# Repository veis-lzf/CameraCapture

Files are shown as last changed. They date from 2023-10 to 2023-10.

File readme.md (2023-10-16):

# 语音拍照存储系统

[TOC]

## 简介

- 基于STM32F407+OV2640进行图像采集，然后存储到TF卡中，通过SU-03T语音识别模块对系统进行控制拍照，灯光开关等操作；

- 主要涉及的知识面：

  （1）串口、定时器的使用

  （2）DCMI总线

  （3）SDIO总线

  （4）DMA技术

  （5）单片机原理图和4层PCB设计

  （6）FATFS文件系统

  （6）Trace日志的使用还有串口协议（十六进制串、AT指令）解析

- 目前支持的语音指令：开灯、关灯、一档光、二档光、三档光、拍照

- 语音模块支持二次开发

------

## 系统和电源框图

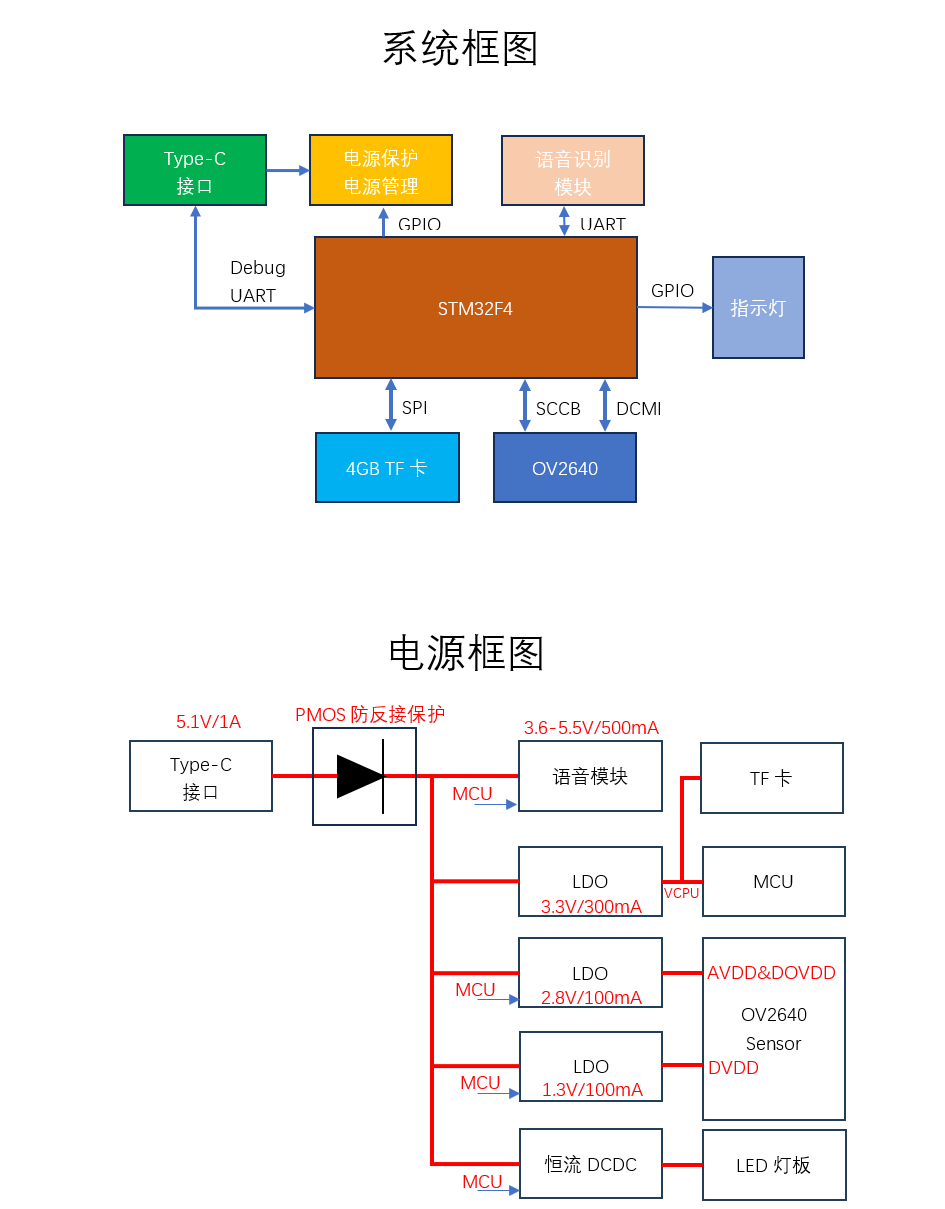
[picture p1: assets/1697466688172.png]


------

## 实物照片

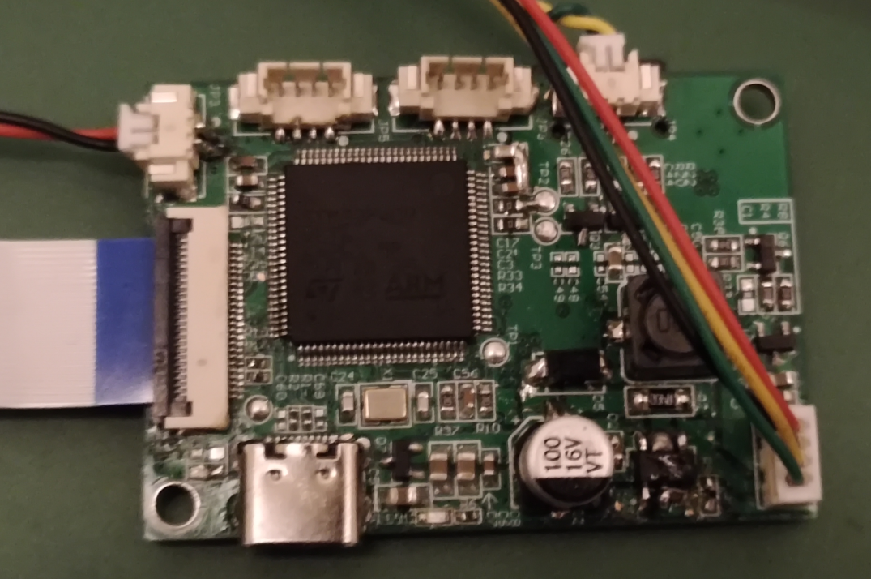
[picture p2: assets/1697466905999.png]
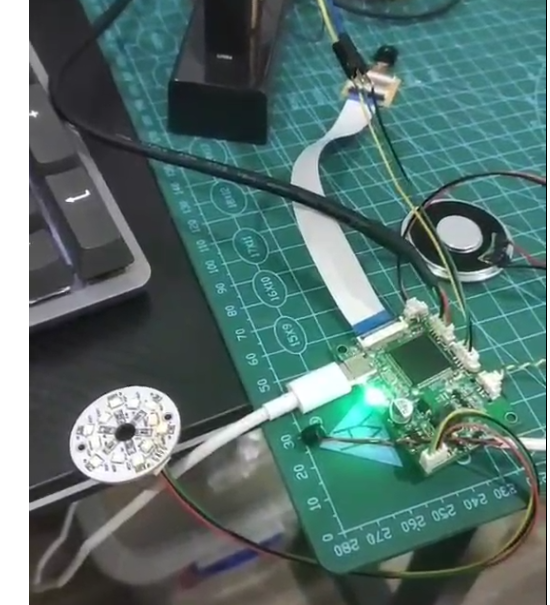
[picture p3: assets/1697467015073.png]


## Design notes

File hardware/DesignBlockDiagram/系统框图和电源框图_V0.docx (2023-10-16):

STM32F4

4GB TF卡

OV2640

SPI

DCMI

SCCB

Type-C

接口

电源保护

电源管理

语音识别

模块

SU-03T

GPIO

UART

指示灯

GPIO

Debug UART

系统框图

Type-C

接口

电源框图

5.1V/1A

语音模块

LDO

3.6-5.5V/500mA

PMOS防反接保护

MCU

3.3V/300mA

LDO

OV2640

Sensor

2.8V/100mA

LDO

1.3V/100mA

DVDD

AVDD&DOVDD

MCU

MCU

MCU

TF卡

VCPU

恒流DCDC

MCU

LED灯板

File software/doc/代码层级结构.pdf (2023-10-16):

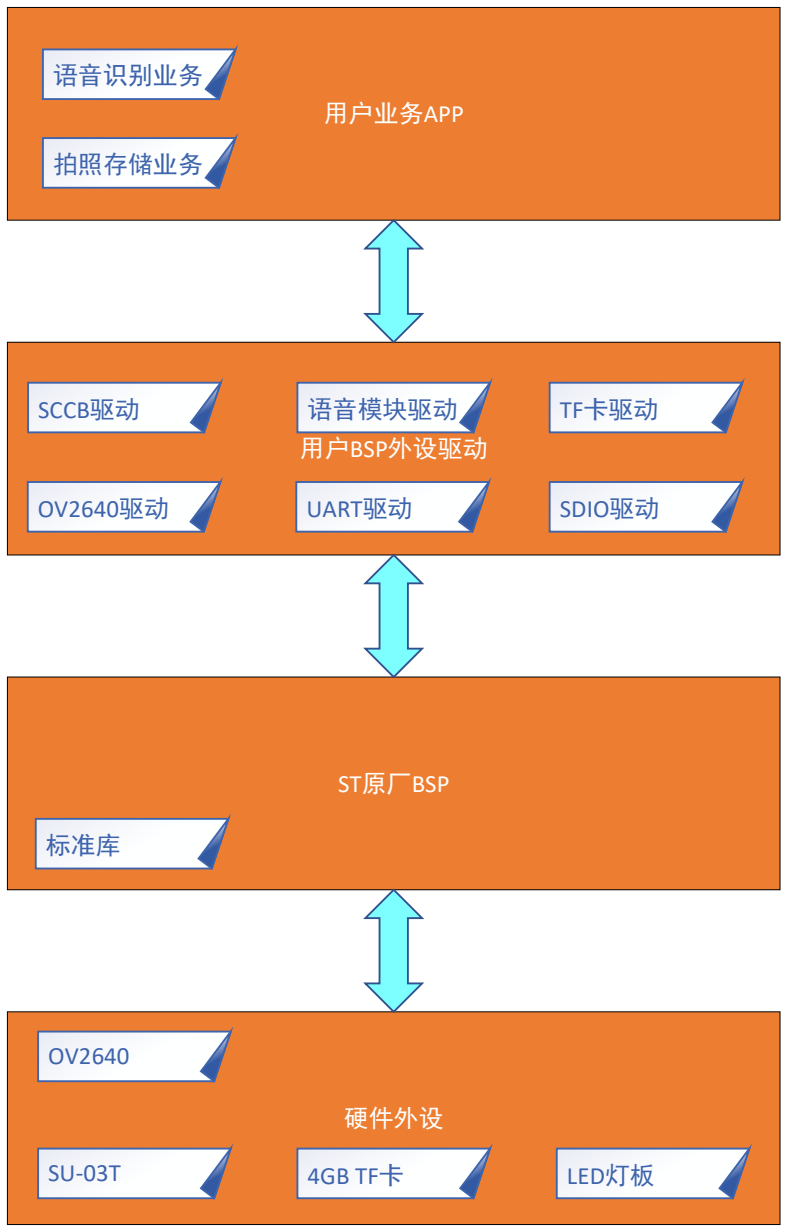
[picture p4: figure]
硬件外设; ST原厂BSP; 用户BSP外设驱动; 用户业务APP; SCCB驱动; 语音模块驱动; UART驱动; SDIO驱动; TF卡驱动; 拍照存储业务; 语音识别业务; 标准库; 4GB TF卡; LED灯板

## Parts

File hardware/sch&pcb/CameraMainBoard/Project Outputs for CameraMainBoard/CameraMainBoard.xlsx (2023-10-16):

Comment | Description | Designator | Footprint | Quantity
1uF | 贴片电容/MLCC电容 | C2, C42 | C0603_M | 2 | 已买
2.2uF | 贴片电容/MLCC电容 | C3, C14, C26 | C0603_M | 3 | 已买
22uF | 贴片电容/MLCC电容 | C5, C6, C7 | C0805_M | 3 | 已买
100nF | 贴片电容/MLCC电容 | C4，C8, C10, C12, C16, C18, C19, C20, C21, C22, C23, C28, C30, C34, C36, C40, C41, C43, C47, C56, C58 | C0603_M | 21 | 已买
10uF | 贴片电容/MLCC电容 | C9, C11, C15, C17, C27, C29, C33, C35, C39, C46, C57 | C0603_M | 11 | 已买
12pF | 贴片电容/MLCC电容 | C24, C25 | C0603_M | 2
SS34 | 肖特基二极管 | D5 | SMA | 1
100uF/16V | 贴片固态电容 | E2 | CS 6*6 - B | 1
TF_Card | TF卡座 | J1 | Micro SD | 1
HDR-1X4 | 4P连接器 | JP1 | MX1.25-L-4P | 1
HDR-1X2 | 2P连接器 | JP3, JP4 | MX1.25-WT-2P | 2
HDR-1X4 | 4P连接器 | JP5, JP6 | MX1.25-LT-4P | 2
33uH | CDRH功率屏蔽电感 | L2 | CDRH74 | 1
电源指示灯 | 贴片LED | LED1 | LED0603_G | 1
SI2301 | P沟道 20V/2.8A | Q1, Q2, Q5, Q7 | SOT23-3N | 4
MMBT3904 | 高频放大-NPN型 | Q3, Q4, Q6 | SOT23-3N | 3
10R | 贴片电阻 | R1, R2 | R0402_M | 2
0R | 贴片电阻 | R3, R11, R12, R13, R16, R19, R33, R34 | R0603_M | 8
100K | 贴片电阻 | R4, R20, R21 | R0603_M | 3
1M | 贴片电阻 | R5 | R0603_M | 1
4.7K | 贴片电阻 | R6 | R0402_M | 1
0.1R | 贴片电阻 | R7 | R1206_M | 1
10K | 贴片电阻 | R8, R9, R10, R14, R26, R27, R37, R39 | R0603_M | 8
1K | 贴片电阻 | R22, R23, R24, R25, R38 | R0603_M | 5
47K | 贴片电阻 | R28, R29, R30, R31, R32 | R0603_M | 5
10R | 贴片电阻 | R35 | R0603_M | 1
XC6228D332VR-G | LDO 1.8V/0.3A | U1 | SOT-23-5 | 1
STM32F407VET6 | ARM Cortex-M4 32b MCU+FPU, 210DMIP, 512 kB Flash, 192+4 kB RAM, Camera, 82 I/Os, 100-pin LQFP, -40 to +85癈, Tray | U2 | LQFP100_V | 1
NS4115 | NS4115 LED恒流驱动IC，最大输出电流1A，输入支持PWM调光 | U4 | SOT89-5M | 1
XC6219B132MR | LDO 1.8V/0.3A | U5 | SOT-23-5 | 1
XC6219B282MR | LDO 1.8V/0.3A | U6 | SOT-23-5 | 1
OV2640 |  | U7 | OV2640-24 | 1
SU-03T | 离线语音识别模块V1.8 | U8 | SU-03T | 1
TYPE-C 2.0 -16P | USB2.0_Type-C_16Pin母座 | USBC1 | USB-C-SMD_16P | 1
8M | 4脚无源晶振(谐振器） | X1 | XTAL-3225-4P | 1
24.000Mhz | 有源晶振 | Y1 | XTAL3225 | 1

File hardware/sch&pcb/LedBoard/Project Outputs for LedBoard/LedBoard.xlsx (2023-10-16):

Comment | Description | Designator | Footprint | LibRef | Quantity
HDR-1X4 | 4P连接器 | JP1 | MX1.25-L-4P | Header 4 | 1
2835 | 0.2W 功率LED | LED1, LED2, LED3, LED4, LED5, LED6, LED7, LED8, LED9, LED10, LED11, LED12 | LED 2835-2P | LED-2835 | 12
100R | 贴片电阻 | R1, R2, R3, R4, R5, R6 | R0603_L | R | 6
1R | 贴片电阻 | R7, R8, R9, R10, R11, R12 | R1206_L | R | 6

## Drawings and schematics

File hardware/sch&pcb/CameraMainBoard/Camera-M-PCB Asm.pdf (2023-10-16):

1 | 1
Material | Layer | Thickness Dielectric Material Type | Gerber

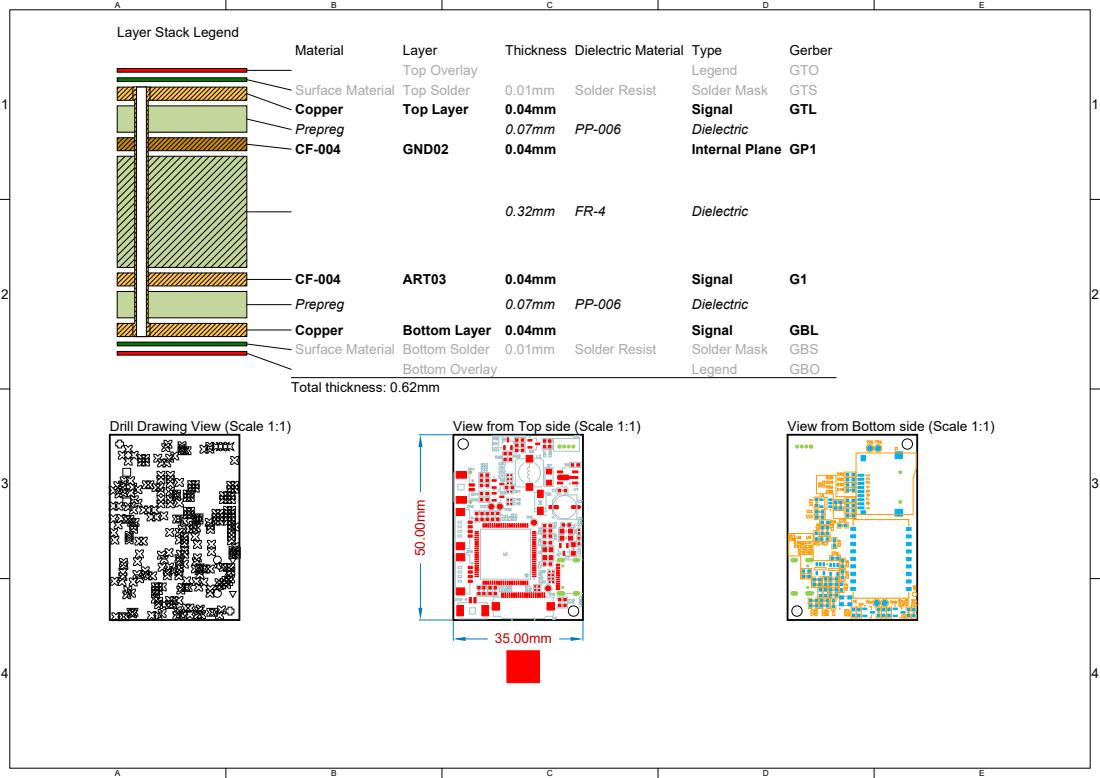
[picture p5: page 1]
Drill Drawing View (Scale 1:1); View from Top side (Scale 1:1); View from Bottom side (Scale 1:1); Top Overlay; Legend; GTO; Surface Material Top Solder; Solder Resist; Solder Mask; GTS; Copper; Top Layer; Signal; GTL; Prepreg; Dielectric; GND02; Internal Plane GP1; ART03; Bottom Layer 0.04mm; GBL; Surface Material Bottom Solder 0.01mm; GBS; Bottom Overlay; GBO; Total thickness: 0.62mm

Layer Stack Legend

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
| Designator | Comment
| C1, C13, C32, C38, C44, C45, C55 | 10nF/NC | Quantity 72313
| C2, C42 | 1uF
| C3, C14, C26 | 2.2uF
Line # 123456789 | C4 | 0.1uF
| C5, C6, C7 | 22uF
| C8, C10, C12, C16, C18, C19, C20, C21, C22, C23, C28, C30, C34, C36, C40, C41, C43, C47, C56, C58 | 100nF | 20
| C9, C11, C15, C17, C27, C29, C33, C35, C39, C46, C57 | 10uF
| C24, C25 | 12pF
| C48, C49, C50, C51, C52, C53, C54, C59, C60 | NC
10 | D5 | SS34
11 | E2 | 100uF/16V
12 | J1 | TF_Card
13 | JP1, JP5, JP6 | HDR-1X4
14 | JP3, JP4 | HDR-1X2
15 | L2 | 33uH
16 | LED1 | 灯灯灯灯灯
17 | Q1, Q2, Q5, Q7 | SI2301
18 | Q3, Q4, Q6 | MMBT3904
19 | R1, R2, R35 | 10R | 1129111321143383131175511221111111111111
20 | R3, R11, R12, R13, R16, R19, R33, R34 | 0R
21 | R4, R20, R21 | 100K
22 | R5 | 1M
23 | R6, R15, R17 | 4.7K
24 | R7 | 0.1R
25 | R8 | 10K
26 | R9, R10, R14, R26, R27, R37, R39 | 10K
27 | R22, R23, R24, R25, R38 | 1K
28 | R28, R29, R30, R31, R32 | 47K
29 | R36 | 4.7K/NC
30 | TP1 | BOOT0
31 | TP2, TP6 | RXD
32 | TP3, TP5 | TXD
33 | TP7 | JTMS
34 | TP8 | JTCK
35 | TP9 | VCPU
36 | U1 | XC6228D332VR-G
37 | U2 | STM32F407VET6
38 | U4 | NS4115
39 | U5 | XC6219B132MR
40 | U6 | XC6219B282MR
41 | U7 | OV2640
42 | U8 | SU-03T
43 | USBC1 | TYPE-C 2.0 -16P
44 | X1 | 8M
45 | Y1 | 24.000Mhz

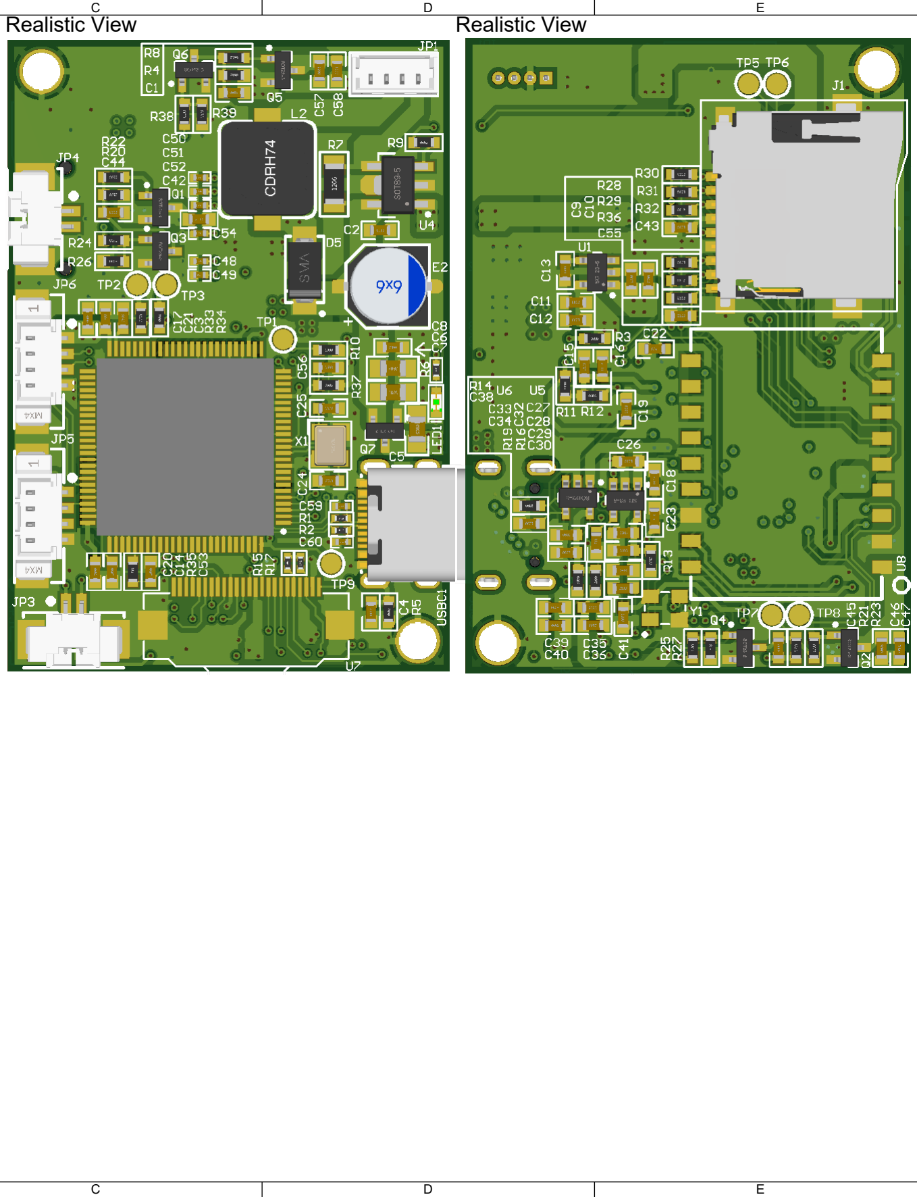
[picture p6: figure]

Bill Of Materials | Realistic View | Realistic View

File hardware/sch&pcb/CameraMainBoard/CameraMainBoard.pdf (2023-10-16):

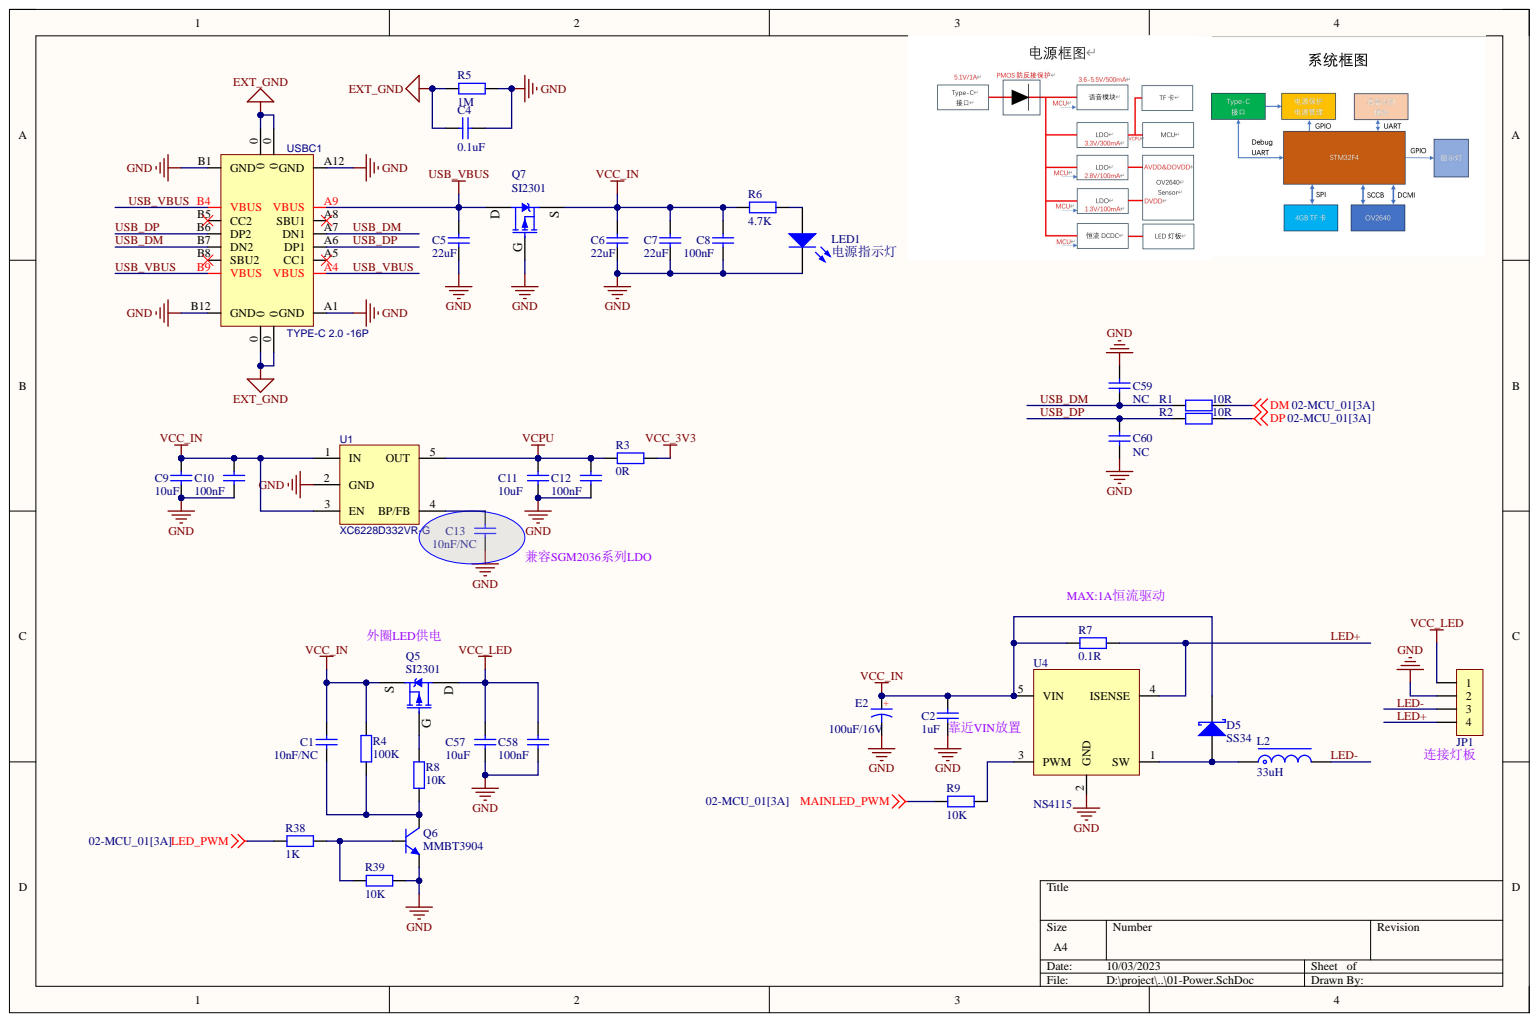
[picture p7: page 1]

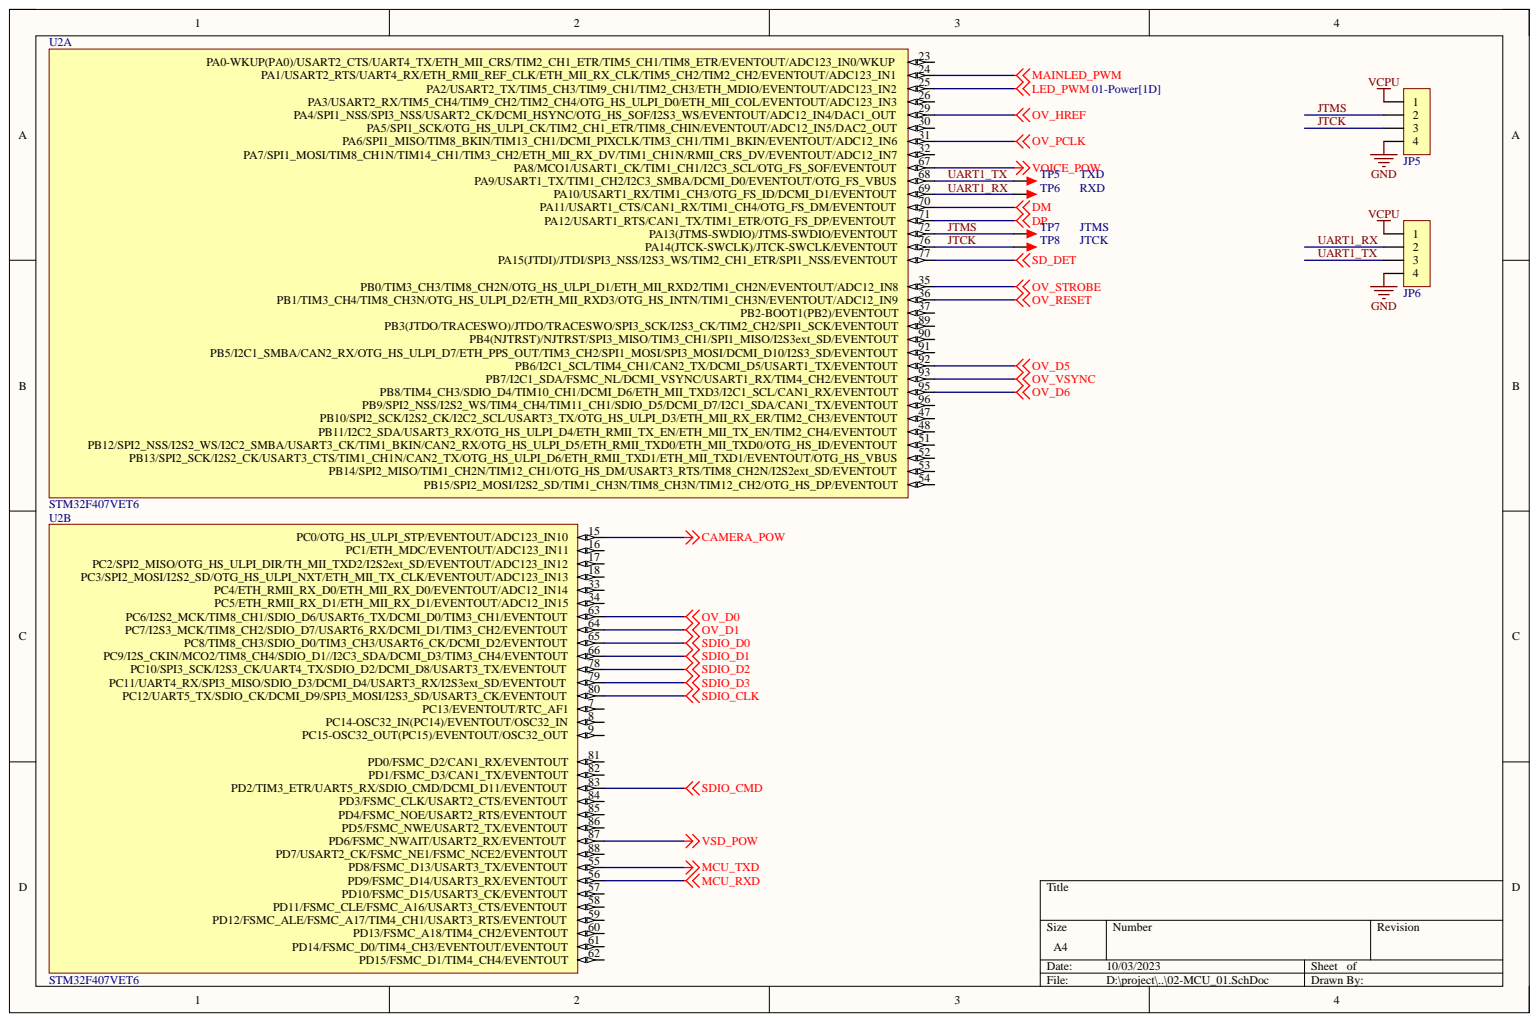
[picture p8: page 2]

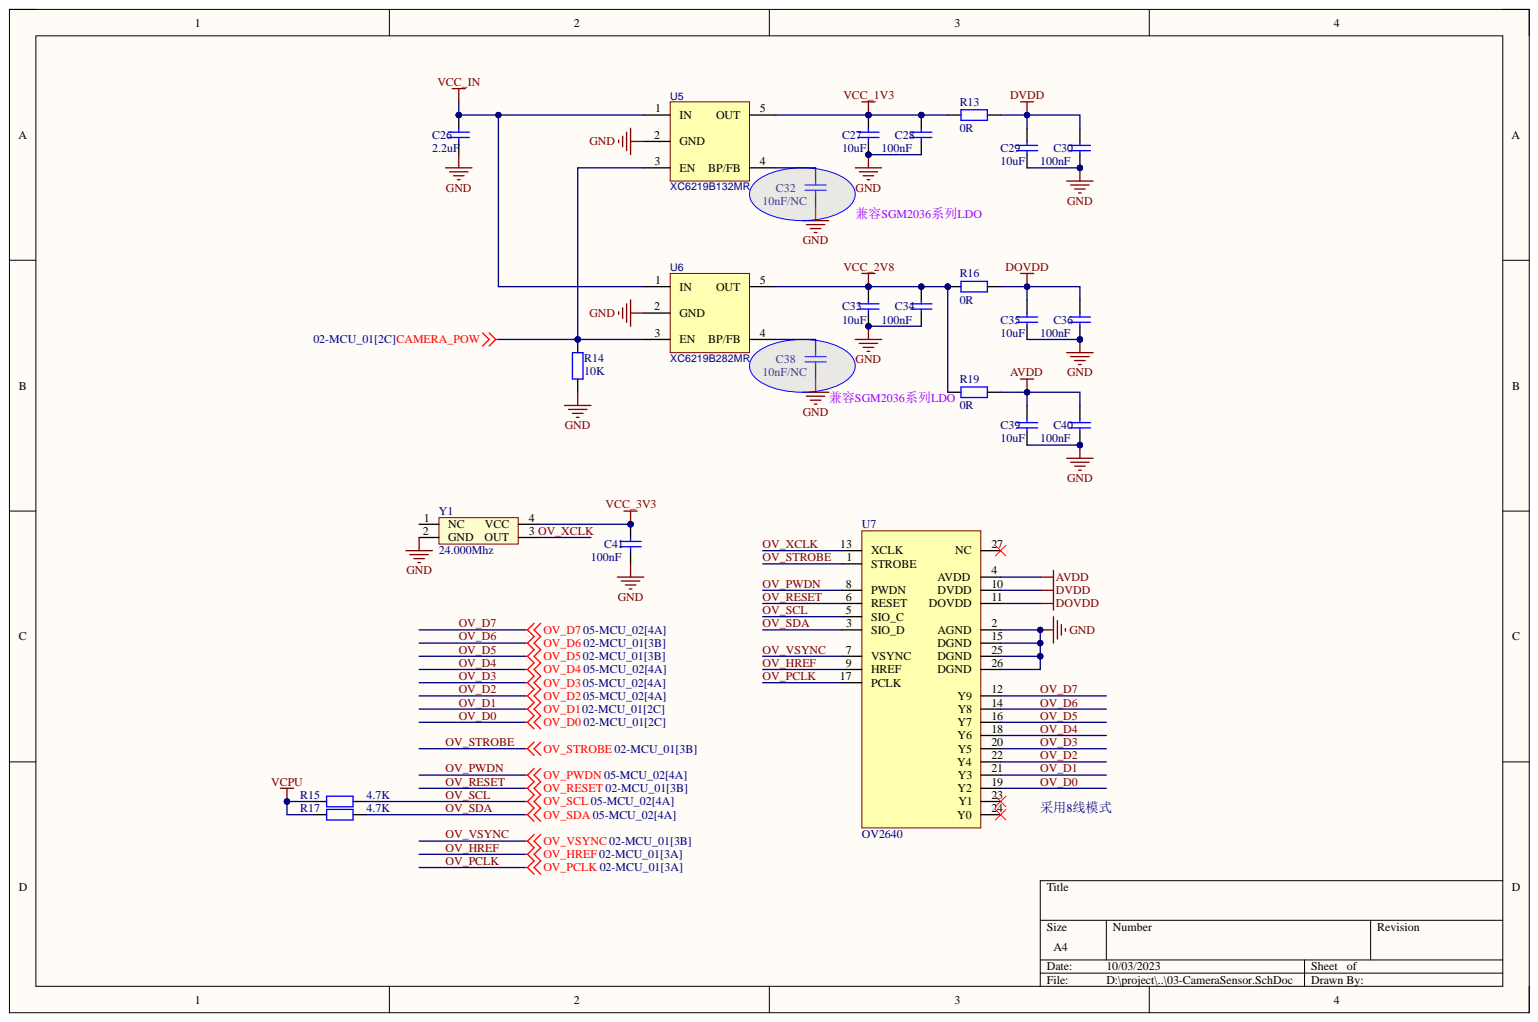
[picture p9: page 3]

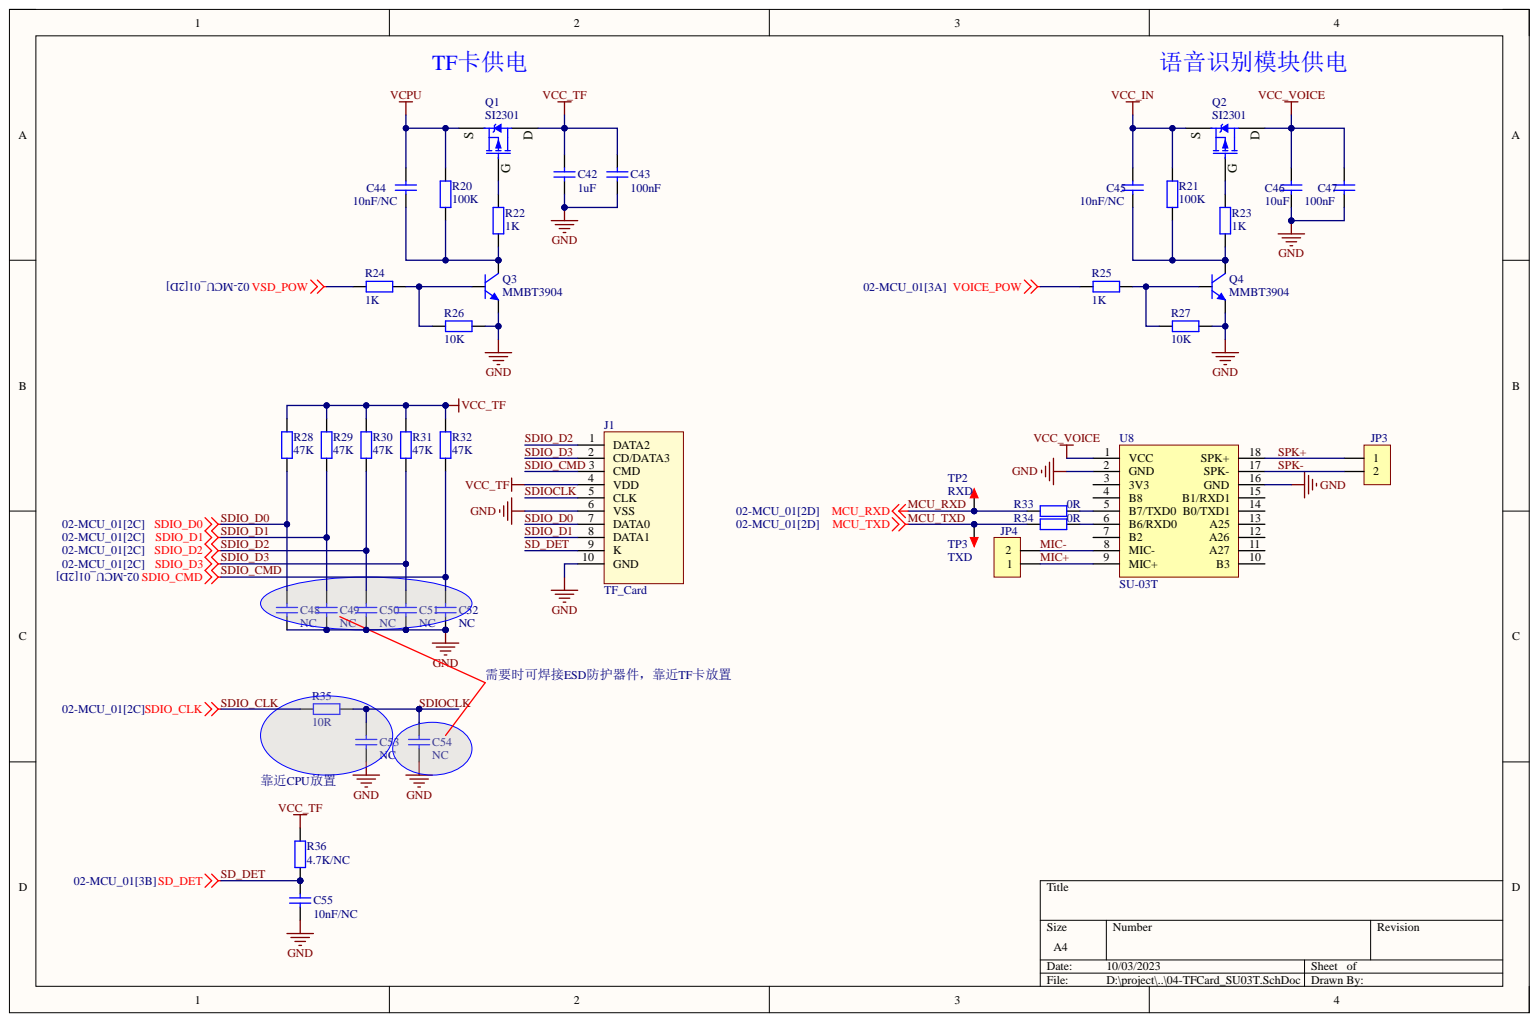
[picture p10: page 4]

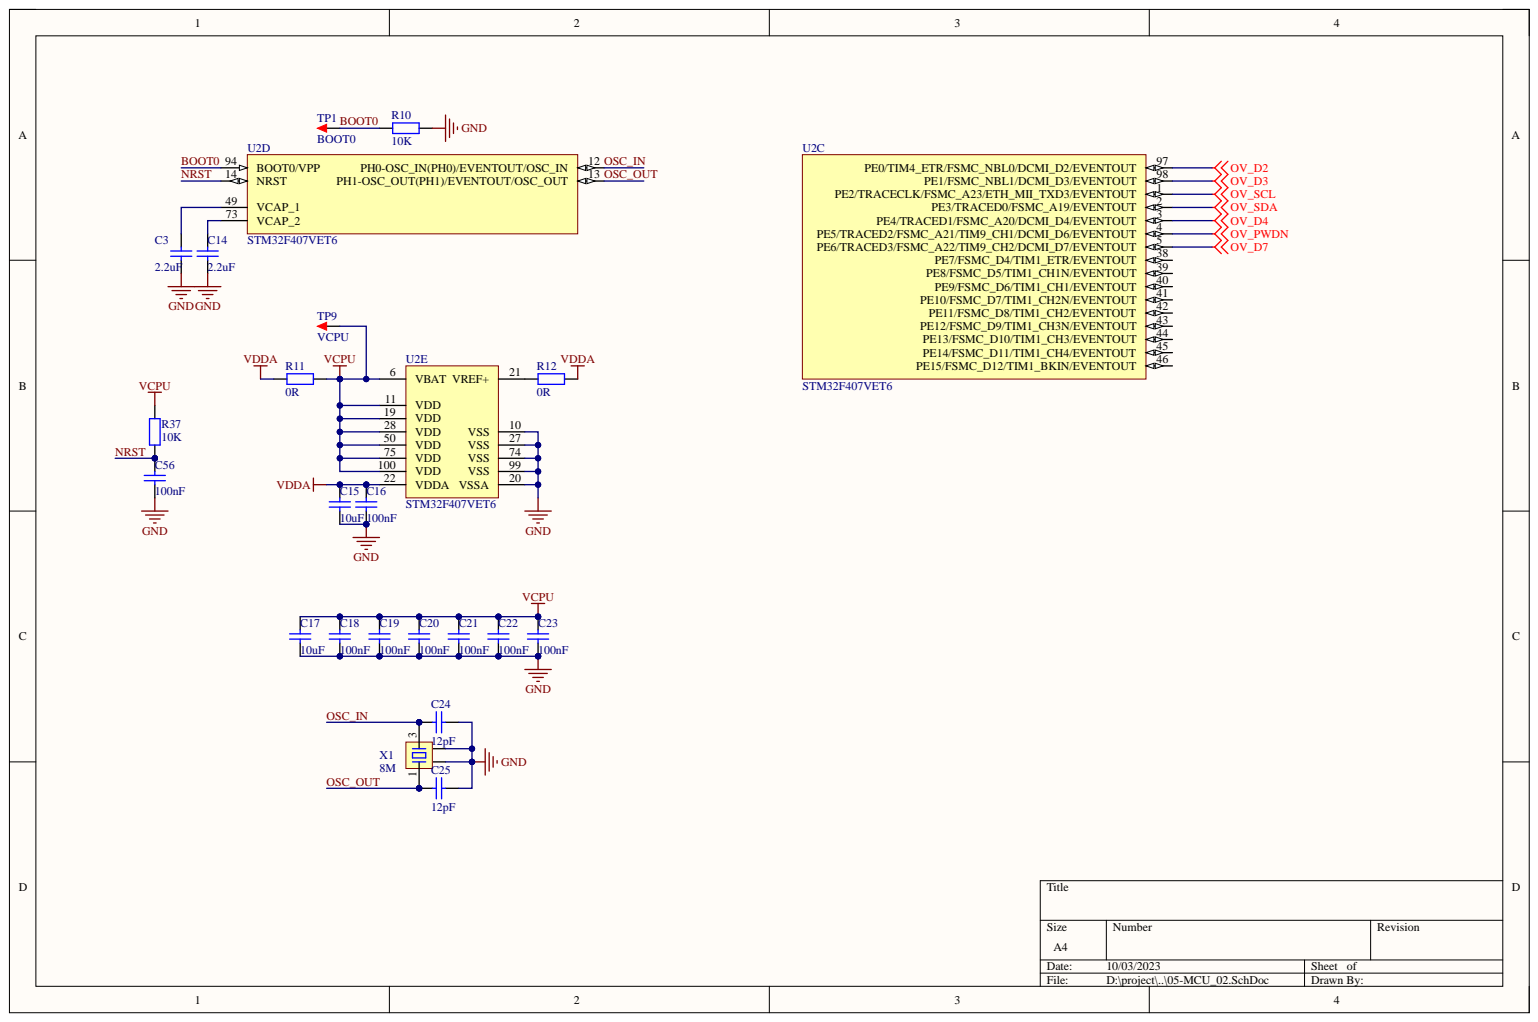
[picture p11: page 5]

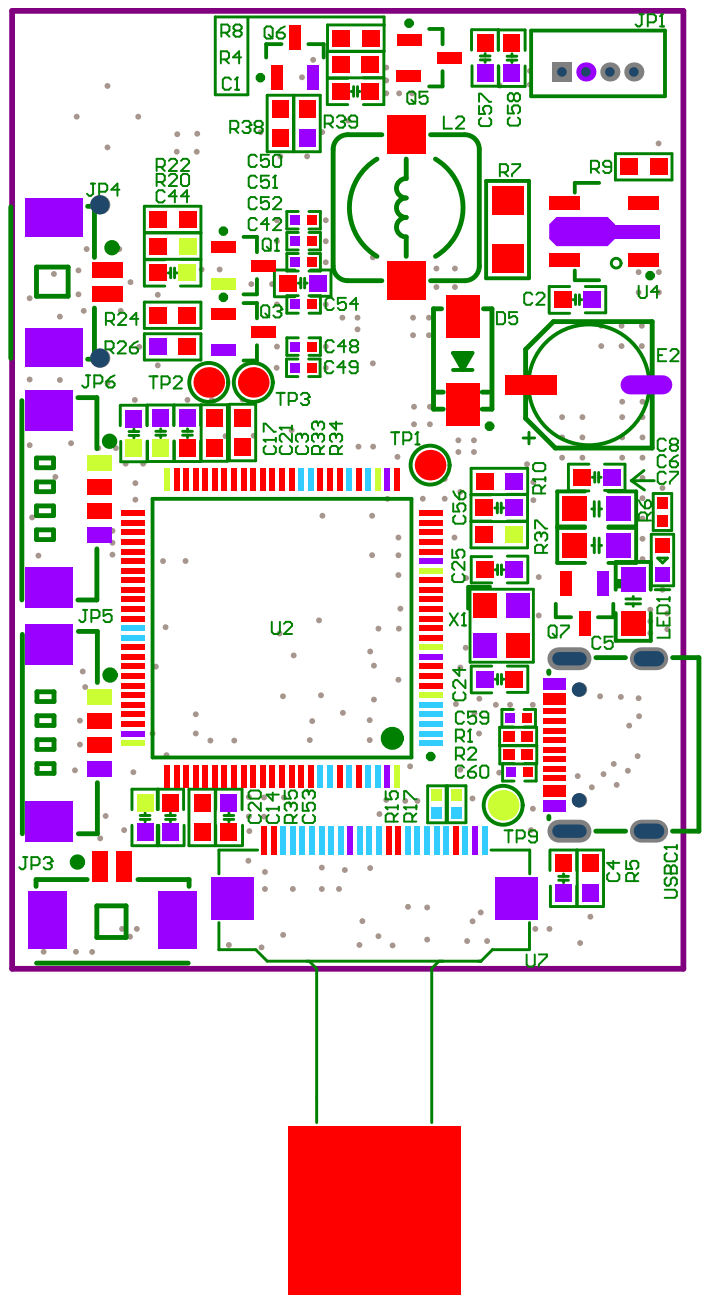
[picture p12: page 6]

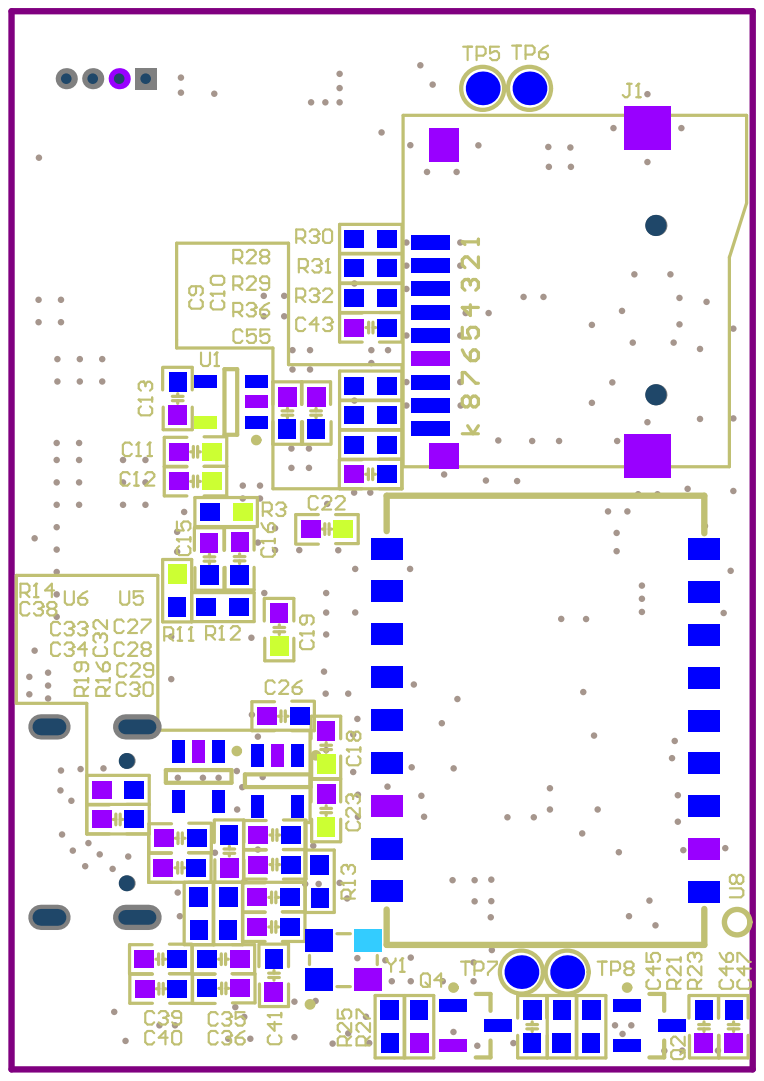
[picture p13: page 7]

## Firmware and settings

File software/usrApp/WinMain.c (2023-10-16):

#include "WinMain.h"
#include "debug.h"

#define VERSION	"V1.0.1"

uint8_t frame_err = 0;

void dcmi_rx_callback(void)
{
	uint32_t i;
	uint32_t *pbuf;
	pbuf = jpeg_data_buf + jpeg_data_len;//偏移到有效数据末尾
	if(DMA2_Stream1->CR&(1<<19))//buf0已满,正常处理buf1
	{ 
		for(i=0;i<jpeg_dma_bufsize;i++)pbuf[i] = jpeg_buf0[i];//读取buf0里面的数据
		jpeg_data_len += jpeg_dma_bufsize;//偏移
	}else //buf1已满,正常处理buf0
	{
		for(i=0;i<jpeg_dma_bufsize;i++)pbuf[i] = jpeg_buf1[i];//读取buf1里面的数据
		jpeg_data_len += jpeg_dma_bufsize;//偏移 
	} 	
}

void Capture_CpltCallback(void)
{
	uint32_t i;
	uint32_t rlen; // 剩余数据长度
	uint32_t *pbuf;
	if(jpeg_data_ok == CAPTURE_BUSY) // jpeg数据还未采集完?
    {	
		DMA_Cmd(DMA2_Stream1,DISABLE);		// 停止当前传输
		while(DMA_GetCmdStatus(DMA2_Stream1) != DISABLE);	// 等待DMA2_Stream1可配置 
		rlen=jpeg_dma_bufsize-DMA_GetCurrDataCounter(DMA2_Stream1); // 得到剩余数据长度	
		pbuf=jpeg_data_buf+jpeg_data_len; // 偏移到有效数据末尾,继续添加
		if(DMA2_Stream1->CR&(1<<19))
			for(i=0;i<rlen;i++)pbuf[i]=jpeg_buf1[i];  // 读取buf1里面的剩余数据
		else for(i=0;i<rlen;i++)pbuf[i]=jpeg_buf0[i]; // 读取buf0里面的剩余数据 
		jpeg_data_len+=rlen;			// 加上剩余长度
		jpeg_data_ok = CAPTURE_COMPLETE; // 标记JPEG数据采集完按成,等待其他函数处理
    }
    if(jpeg_data_ok == PROCESS_COMPLETE) // 上一次的jpeg数据已经被处理了
    {
		DMA_SetCurrDataCounter(DMA2_Stream1,jpeg_dma_bufsize); // 传输长度为jpeg_buf_size*4字节
		DMA_Cmd(DMA2_Stream1,ENABLE); // 重新传输
		jpeg_data_ok = CAPTURE_BUSY;  // 标记数据未采集
		jpeg_data_len = 0;			  // 数据重新开始
	}
}

static void init(void *param)
{
	RCC_ClocksTypeDef RCC_ClocksStatus;

	driver_misc_init();	  // 初始化系统时基/GPIO时钟/NVIC分组
	usr_gpio_init(); 	  // 初始化外设端口	
	my_mem_init(SRAMIN);  // 初始化内部内存池 
	my_mem_init(SRAMCCM); // 初始化CCM内存池
	misc_init(); // 初始化外设驱动
	
	jpeg_buf0 = mymalloc(SRAMIN,jpeg_dma_bufsize*4);	//为jpeg dma接收申请内存	
	jpeg_buf1 = mymalloc(SRAMIN,jpeg_dma_bufsize*4);	//为jpeg dma接收申请内存	
	jpeg_data_buf = mymalloc(SRAMIN, 30*1024);		//为jpeg文件申请内存(最大300KB)
	pname = mymalloc(SRAMIN,30); // 为带路径的文件名分配30个字节的内存
	
	// 打印复位原因
//	check_rst_stat();
	// 打印系统频率
	RCC_GetClocksFreq(&RCC_ClocksStatus);
	p_dbg(
		"\r\nVERSION:%s\r\n"
		"SYSCLK_Frequency:%d\r\n"
		"HCLK_Frequency:%d\r\n"
		"PCLK1_Frequency:%d\r\n"
		"PCLK2_Frequency:%d\r\n",
		VERSION,
		RCC_ClocksStatus.SYSCLK_Frequency, 
		RCC_ClocksStatus.HCLK_Frequency, 
		RCC_ClocksStatus.PCLK1_Frequency, 
		RCC_ClocksStatus.PCLK2_Frequency);
		
	Init_SDCARD();
	
	uint8_t timeout = 0;
	while(OV2640_Init() && timeout < 10)
	{
		timeout++;
		gpio_set_level((uint32_t)CAMERA_PWR_PORT_GROUP, CAMERA_PWR_PIN, LOW_LEVEL);
		delay_ms(200);
		gpio_set_level((uint32_t)CAMERA_PWR_PORT_GROUP, CAMERA_PWR_PIN, HIGH_LEVEL);
		delay_ms(200);
	}
	if(timeout == 10)
	{
		p_err("ov2640 init failed!");
		soft_reset();
	}
}

//#define JPEG_UART_TX_TEST
#ifdef JPEG_UART_TX_TEST
// JPEG测试
// JPEG数据,通过串口1发送给电脑.
void jpeg_test(void)
{	
	uint32_t i, jpeg_start, jpeg_len, jpeg_ok;; 
	uint8_t *p;
	
	DCMI_DMA_Init((u32)jpeg_buf0,(u32)jpeg_buf1,jpeg_dma_bufsize,DMA_MemoryDataSize_Word,DMA_MemoryInc_Enable);//DCMI DMA配置(双缓冲模式)
	Init_JPEG(eType_QVGA);
	OV2640_JPEG_Mode();		//切换为JPEG模式 
	DCMI_Start(); 			//启动传输 
	while(1)
	{
		IWDG_Feed();
		if(jpeg_data_ok==1)	// 已经采集完一帧图像了
		{  
			p=(uint8_t*)jpeg_data_buf;
			for(i=0;i<jpeg_data_len*4;i++)//查找0XFF,0XD8
			{
				//printf("%x ", pbuf[i]);
				if((p[i]==0XFF)&&(p[i+1]==0XD8))
				{
					jpeg_start = i;
				}
				if((p[i]==0XFF)&&(p[i+1]==0XD9))
				{
					jpeg_len = i - jpeg_start + 2;
					jpeg_ok = 1;
					break;
				}
			}
			
			if(jpeg_ok)
			{
				p += jpeg_start;
				for(i=0;i<jpeg_len;i++)		                            // dma传输1次等于4字节,所以乘以4.
				{
					while(USART_GetFlagStatus(USART1,USART_FLAG_TC)==RESET);	// 循环发送,直到发送完毕  		
					USART_SendData(USART1,p[i]); 
					IWDG_Feed();
				}
			}
			else
			{
				frame_err++;
			}
			jpeg_data_ok=2;
		} 
    }
} 
#endif

uint8_t run_status = 0;
static void run(void *param)
{
	DCMI_DMA_Init((u32)jpeg_buf0,(u32)jpeg_buf1,jpeg_dma_bufsize,DMA_MemoryDataSize_Word,DMA_MemoryInc_Enable);//DCMI DMA配置(双缓冲模式)
	Init_JPEG(eType_QVGA);
	OV2640_JPEG_Mode();		//切换为JPEG模式 
	DCMI_Start(); 			//启动传输
	
	WDT_init(IWDG_Prescaler_256, 500); // 预分频数为64,重载值为500,溢出时间为1s
	
	while(1)
	{
		IWDG_Feed();
		delay_ms(1*1000);
	#ifdef JPEG_UART_TX_TEST
		jpeg_test();
	#endif
	}
}

WinMainStruct mainTask =
{
	init,
	run,
};

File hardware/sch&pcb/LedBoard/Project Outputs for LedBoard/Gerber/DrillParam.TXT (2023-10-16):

M48
;Layer_Color=9474304
;FILE_FORMAT=4:4
METRIC,LZ
;TYPE=PLATED
T1F00S00C0.5000
%
T01
X0010795Y0005207
X0009984Y00061582
X0009173Y00071094
X00083619Y00080606
M30

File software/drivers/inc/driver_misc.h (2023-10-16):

#ifndef __DRIVER_MISC_H__
#define __DRIVER_MISC_H__

#include "type.h"

///////////////////////////////////////////////////////////////////////////////////////////////////////////////
#define GPIO_SET(port,pin) (port->BSRRL = pin)
#define GPIO_CLR(port,pin) (port->BSRRH = pin)
#define GPIO_STAT(port,pin)(!!(port->IDR & pin))

typedef enum 
{
	LOW_LEVEL = 0,
	HIGH_LEVEL,
} GPIO_Level;
///////////////////////////////////////////////////////////////////////////////////////////////////////////////

#define SD_CARD_STATUS_ERROR	0
#define SD_CARD_STATUS_OK		1

//define UART PORT
// 用于调试日志输出
#define UART1_RX_PORT_GROUP 		GPIOA
#define UART1_TX_PORT_GROUP 		GPIOA
#define UART1_TX_PIN 				GPIO_Pin_9
#define UART1_RX_PIN 				GPIO_Pin_10
#define UART1_TX_PIN_SOURSE			GPIO_PinSource9
#define UART1_RX_PIN_SOURSE			GPIO_PinSource10

// 用于语音模块
#define UART3_RX_PORT_GROUP 		GPIOD
#define UART3_TX_PORT_GROUP 		GPIOD
#define UART3_TX_PIN 				GPIO_Pin_8
#define UART3_RX_PIN 				GPIO_Pin_9
#define UART3_TX_PIN_SOURSE			GPIO_PinSource8
#define UART3_RX_PIN_SOURSE			GPIO_PinSource9

//define USB PORT

#define USB_DP_PORT_GROUP 		GPIOA
#define USB_DM_PORT_GROUP 		GPIOA

#define USB_DP_PIN 				GPIO_Pin_12
#define USB_DM_PIN 				GPIO_Pin_11

#define USB_DP_PIN_SOURSE		GPIO_PinSource12
#define USB_DM_PIN_SOURSE		GPIO_PinSource11

//define sdio PORT

#define SDIO_CLK_PORT				GPIOC
#define SDIO_CLK_PIN				GPIO_Pin_12
#define SDIO_CLK_SOURCE				GPIO_PinSource12

#define SDIO_D0_PORT				GPIOC
#define SDIO_D0_PIN					GPIO_Pin_8
#define SDIO_D0_SOURCE				GPIO_PinSource8

#define SDIO_D1_PORT				GPIOC
#define SDIO_D1_PIN					GPIO_Pin_9
#define SDIO_D1_SOURCE				GPIO_PinSource9

#define SDIO_D2_PORT				GPIOC
#define SDIO_D2_PIN					GPIO_Pin_10
#define SDIO_D2_SOURCE				GPIO_PinSource10

#define SDIO_D3_PORT				GPIOC
#define SDIO_D3_PIN					GPIO_Pin_11
#define SDIO_D3_SOURCE				GPIO_PinSource11

#define SDIO_CMD_PORT				GPIOD
#define SDIO_CMD_PIN				GPIO_Pin_2
#define SDIO_CMD_SOURCE				GPIO_PinSource2

#define SD_DET_PORT					GPIOA
#define SD_DET_PIN					GPIO_Pin_15
#define SD_DET_SOURCE				GPIO_PinSource15
//end define sdio PORT

//define DCMI PORT
#define DCMI_HS_PORT_GROUP 			GPIOA
#define DCMI_HS_PIN 				GPIO_Pin_4
#define DCMI_HS_SOURCE 				GPIO_PinSource4

#define DCMI_VS_PORT_GROUP 			GPIOB
#define DCMI_VS_PIN 				GPIO_Pin_7
#define DCMI_VS_SOURCE 				GPIO_PinSource7

#define DCMI_PCLK_PORT_GROUP 		GPIOA
#define DCMI_PCLK_PIN 				GPIO_Pin_6
#define DCMI_PCLK_SOURCE 			GPIO_PinSource6

#define DCMI_D0_PORT_GROUP 			GPIOC
#define DCMI_D0_PIN 				GPIO_Pin_6
#define DCMI_D0_SOURCE 				GPIO_PinSource6

#define DCMI_D1_PORT_GROUP 			GPIOC
#define DCMI_D1_PIN 				GPIO_Pin_7
#define DCMI_D1_SOURCE 				GPIO_PinSource7
		
#define DCMI_D2_PORT_GROUP 			GPIOE
#define DCMI_D2_PIN 				GPIO_Pin_0
#define DCMI_D2_SOURCE 				GPIO_PinSource0
		
#define DCMI_D3_PORT_GROUP 			GPIOE
#define DCMI_D3_PIN 				GPIO_Pin_1
#define DCMI_D3_SOURCE 				GPIO_PinSource1
		
#define DCMI_D4_PORT_GROUP 			GPIOE
#define DCMI_D4_PIN 				GPIO_Pin_4
#define DCMI_D4_SOURCE 				GPIO_PinSource4
		
#define DCMI_D5_PORT_GROUP 			GPIOB
#define DCMI_D5_PIN 				GPIO_Pin_6
#define DCMI_D5_SOURCE 				GPIO_PinSource6
		
#define DCMI_D6_PORT_GROUP 			GPIOB
#define DCMI_D6_PIN 				GPIO_Pin_8
#define DCMI_D6_SOURCE 				GPIO_PinSource8
		
#define DCMI_D7_PORT_GROUP 			GPIOE
#define DCMI_D7_PIN 				GPIO_Pin_6
#define DCMI_D7_SOURCE 				GPIO_PinSource6

// 摄像头采用外部晶振，不配置此时钟输出
#define MCO_PORT_GROUP 		 		NULL
#define MCO_PIN 					NULL
#define MCO_PIN_SOURCE 				NULL

// 闪光灯控制引脚（预留）
#define STROBE_PORT_GROUP 		 	GPIOB
#define STROBE_PIN 					GPIO_Pin_0

#define DCMI_RST_PORT_GROUP 		GPIOB
#define DCMI_RST_PIN 				GPIO_Pin_1
	
#define DCMI_PWD_PORT_GROUP 		GPIOE
#define DCMI_PWD_PIN				GPIO_Pin_5
	
#define SIO_C_PORT_GROUP 			GPIOE
#define SIO_C_PIN 					GPIO_Pin_2
	
#define SIO_D_PORT_GROUP 			GPIOE
#define SIO_D_PIN 					GPIO_Pin_3

#define SIO_D_OUT					gpio_cfg((uint32_t)SIO_D_PORT_GROUP, SIO_D_PIN, GPIO_Mode_Out_PP);
#define SIO_D_IN					gpio_cfg((uint32_t)SIO_D_PORT_GROUP, SIO_D_PIN, GPIO_Mode_IPU);

//end define DCMI PORT

//define power PORT

// 摄像头电源使能，高开低关
#define CAMERA_PWR_PORT_GROUP 		GPIOC
#define CAMERA_PWR_PIN 				GPIO_Pin_0

// TF卡电源使能，高开低关
#define VSD_POW_PORT_GROUP			GPIOD
#define VSD_POW_PIN 				GPIO_Pin_6

// SU-03T语音识别模块电源使能，高开低关
#define VOICE_POW_PORT_GROUP		GPIOA
#define VOICE_POW_PIN 				GPIO_Pin_8

//end define power PORT

//define pwm PORT
#define MAIN_LED_PWM_PORT_GROUP		GPIOA
#define MAIN_LED_PWM_PIN			GPIO_Pin_1
#define MAIN_LED_PWM_SOURCE 		GPIO_PinSource1
#define MAIN_LED_PWM_AF				GPIO_AF_TIM2

#define LED_PWM_PORT_GROUP			GPIOA
#define LED_PWM_PIN					GPIO_Pin_2
#define LED_PWM_SOURCE 				GPIO_PinSource2
#define LED_PWM_AF					GPIO_AF_TIM2

//end define pwm PORT

void gpio_cfg(uint32_t group, uint32_t pin, uint8_t mode);
void gpio_set_level(uint32_t group, uint32_t pin, GPIO_Level level);
void usr_gpio_init(void);
int check_rst_stat(void);
void driver_misc_init(void);
uint32_t get_random(void);
void driver_gpio_init(void);
void _mem_init(void);
uint32_t get_us_count(void);

#endif

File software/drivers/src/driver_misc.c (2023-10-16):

#define DEBUG

#include "debug.h"
#include "drivers.h"
#include "app.h"

#include <absacc.h>

// 系统节拍
#define OS_TICK_RATE_HZ	(1000)

extern char Image$$RW_IRAM1$$ZI$$Limit[];
void _mem_init(void)
{
#if 0
	uint32_t malloc_start, malloc_size;

	malloc_start = (uint32_t) &Image$$RW_IRAM1$$ZI$$Limit; //取空闲内存最低地址
	malloc_start = (malloc_start + 3) & (~0x03);// ALIGN TO word

	// 0x20000为板子内存总大小，更换MCU时需注意
	// malloc_size = 0x20000000 + (128*1024) - malloc_start;
	// @veis20230416, stm32f427vit6 sram size=256(112+16+64+64(ccm))KB
	malloc_size = 0x20000000 + (192*1024) - malloc_start;

/*
*407有64k的高速ram(地址0x10000000)，由于其不能用于DMA等外设使用，所以不建议放入内存池
*建议手动分配使用
*/
	sys_meminit((void*)0x10000000, 0x10000, (void*)malloc_start, malloc_size);
	sys_meminit((void*)malloc_start, malloc_size);
	sys_meminit2((void*)0x10000000, 0x10000);
#endif
}

void init_systick()
{
	NVIC_PriorityGroupConfig(NVIC_PriorityGroup_4);
	SysTick_Config(SystemCoreClock / (OS_TICK_RATE_HZ));
}

void init_rng()
{
	RCC_AHB2PeriphClockCmd(RCC_AHB2Periph_RNG, ENABLE);
	RNG_Cmd(ENABLE);
}

/**
 *读一个随机数
 */
uint32_t get_random(void)
{
	return RNG_GetRandomNumber();
}

/**
 * 配置GPIO
 */
void gpio_cfg(uint32_t group, uint32_t pin, uint8_t mode)
{
	GPIO_InitTypeDef GPIO_InitStructure;
	
	GPIO_InitStructure.GPIO_Pin = pin;
	GPIO_InitStructure.GPIO_Speed = GPIO_Speed_100MHz;
	
	if (mode == GPIO_Mode_AIN)
	{
		GPIO_InitStructure.GPIO_Mode = GPIO_Mode_AN;
		GPIO_InitStructure.GPIO_OType = GPIO_OType_OD;
		GPIO_InitStructure.GPIO_PuPd = GPIO_PuPd_NOPULL;
	}
	else if (mode == GPIO_Mode_IN_FLOATING)
	{
		GPIO_InitStructure.GPIO_Mode = GPIO_Mode_IN;
		GPIO_InitStructure.GPIO_OType = GPIO_OType_OD;
		GPIO_InitStructure.GPIO_PuPd = GPIO_PuPd_NOPULL;
	}
	else
	if (mode == GPIO_Mode_IPD)
	{
		GPIO_InitStructure.GPIO_Mode = GPIO_Mode_IN;
		GPIO_InitStructure.GPIO_OType = GPIO_OType_OD;
		GPIO_InitStructure.GPIO_PuPd = GPIO_PuPd_DOWN;
	}
	else
	if (mode == GPIO_Mode_IPU)
	{
		GPIO_InitStructure.GPIO_Mode = GPIO_Mode_IN;
		GPIO_InitStructure.GPIO_OType = GPIO_OType_OD;
		GPIO_InitStructure.GPIO_PuPd = GPIO_PuPd_UP;
	}
	else
	if (mode == GPIO_Mode_Out_OD)
	{
		GPIO_InitStructure.GPIO_Mode = GPIO_Mode_OUT;
		GPIO_InitStructure.GPIO_OType = GPIO_OType_OD;
		GPIO_InitStructure.GPIO_PuPd = GPIO_PuPd_NOPULL;
	}
	else
	if (mode == GPIO_Mode_Out_PP)
	{
		GPIO_InitStructure.GPIO_Mode = GPIO_Mode_OUT;
		GPIO_InitStructure.GPIO_OType = GPIO_OType_PP;
		GPIO_InitStructure.GPIO_PuPd = GPIO_PuPd_NOPULL;
	}
	else
	if (mode == GPIO_Mode_AF_OD)
	{
		GPIO_InitStructure.GPIO_Mode = GPIO_Mode_AF;
		GPIO_InitStructure.GPIO_OType = GPIO_OType_OD;
		GPIO_InitStructure.GPIO_PuPd = GPIO_PuPd_NOPULL;
	}
	else
	if (mode == GPIO_Mode_AF_PP)
	{
		GPIO_InitStructure.GPIO_Mode = GPIO_Mode_AF;
		GPIO_InitStructure.GPIO_OType = GPIO_OType_PP;
		GPIO_InitStructure.GPIO_PuPd = GPIO_PuPd_UP;
	}
	else
	if (mode == GPIO_Mode_AF_IF)
	{
		GPIO_InitStructure.GPIO_Mode = GPIO_Mode_AF;
		GPIO_InitStructure.GPIO_OType = GPIO_OType_OD;
		GPIO_InitStructure.GPIO_PuPd = GPIO_PuPd_NOPULL;
	}
	else
	if (mode == GPIO_Mode_AF_IPU)
	{
		GPIO_InitStructure.GPIO_Mode = GPIO_Mode_AF;
		GPIO_InitStructure.GPIO_OType = GPIO_OType_OD;
		GPIO_InitStructure.GPIO_PuPd = GPIO_PuPd_UP;
	}
	GPIO_Init((GPIO_TypeDef*)group, &GPIO_InitStructure);
}

void gpio_set_level(uint32_t group, uint32_t pin, GPIO_Level level)
{
	GPIO_WriteBit((GPIO_TypeDef*)group, pin, (BitAction)level);
}

void driver_gpio_init()
{
	RCC_APB2PeriphClockCmd(RCC_APB2Periph_SYSCFG, ENABLE); // 外部中断需要用到
	RCC_AHB1PeriphClockCmd(
		RCC_AHB1Periph_GPIOA | 
		RCC_AHB1Periph_GPIOB | 
		RCC_AHB1Periph_GPIOC | 
		RCC_AHB1Periph_GPIOD | 
		RCC_AHB1Periph_GPIOE, ENABLE);
}

int check_rst_stat()
{
	uint32_t stat;
	stat = RCC->CSR;
	RCC->CSR = 1L << 24; //清除复位标志

	p_err("reset:");
	if (stat &(1UL << 31))
	// 低功耗复位
	{
		p_err("low power\n");
	}
	if (stat &(1UL << 30))
	//窗口看门狗复位
	{
		p_err("windw wdg\n");
	}
	if (stat &(1UL << 29))
	//独立看门狗复位
	{
		p_err("indep wdg\n");
	}
	if (stat &(1UL << 28))
	//软件复位
	{
		p_err("soft reset\n");
	}
	if (stat &(1UL << 27))
	//掉电复位
	{
		p_err("por reset\n");
	}
	if (stat &(1UL << 26))
	//rst复位
	{
		p_err("user reset\n");
	}

	return 0;
}

/*
* TIMER5作为us定时器
*/
void init_us_timer()
{
	TIM_TimeBaseInitTypeDef TIM_TimeBaseStructure;

	RCC_APB1PeriphClockCmd(RCC_APB1Periph_TIM5, ENABLE);

	TIM_DeInit(TIM5); 

	//APB1时钟42M，tim5时钟84M，这里预分频设为840， 每MS计数100，即每个计数是10us
	TIM_TimeBaseStructure.TIM_Period = 0xffffffff;
 	TIM_TimeBaseStructure.TIM_Prescaler = 840;
  	TIM_TimeBaseStructure.TIM_ClockDivision = TIM_CKD_DIV1;
  	TIM_TimeBaseStructure.TIM_CounterMode = TIM_CounterMode_Up;
  	TIM_TimeBaseInit(TIM5, &TIM_TimeBaseStructure);

	TIM_ARRPreloadConfig(TIM5, ENABLE);
	TIM_Cmd(TIM5, ENABLE);
}

uint32_t get_us_count()
{
	return TIM_GetCounter(TIM5)*10;
}

void driver_misc_init()
{
	driver_gpio_init();
	init_systick();
	init_rng();
	init_us_timer();
	EXTIX_Init();
}

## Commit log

2023-10-16 提交V1.0.1版本代码和readme文件
2023-10-16 提交硬件原理图和PCB资料
    [01-Power.SchDoc, 02-MCU_01.SchDoc, 03-CameraSensor.SchDoc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]
